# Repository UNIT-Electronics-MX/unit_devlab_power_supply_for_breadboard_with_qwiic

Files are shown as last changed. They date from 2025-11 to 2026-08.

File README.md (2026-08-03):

# DevLab: Power Supply for Breadboard with QWIIC

The Breadboard Power Supply with Load Decoy and QWIIC Connectors is a compact and versatile module designed to power electronic projects in a practical and safe way. It allows power to be supplied through QWIIC connectors or via USB-C chargers compatible with technologies such as Power Delivery (PD), Quick Charge (QC), or Battery Charging (BC).

<div align="center">
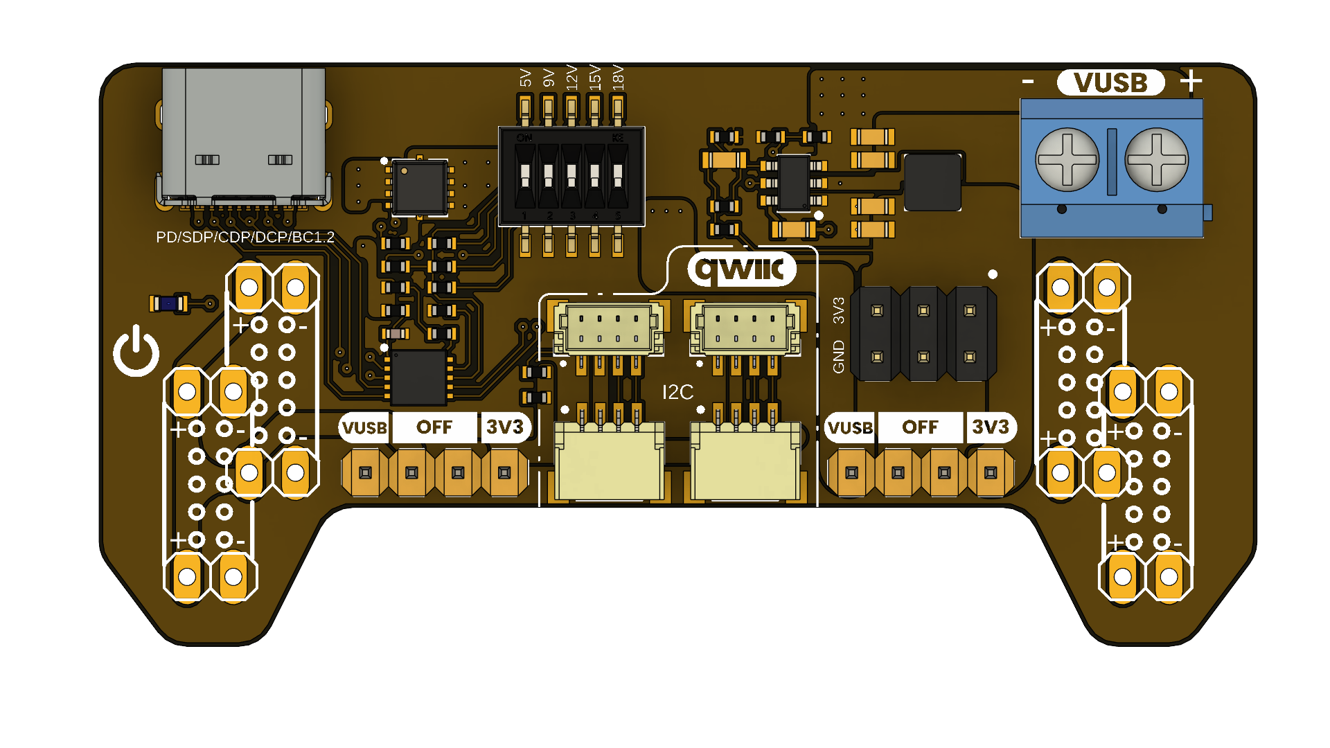
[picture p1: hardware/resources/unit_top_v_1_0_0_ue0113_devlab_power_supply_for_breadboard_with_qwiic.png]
Power Supply for Breadboard with QWIIC
  
  <p><em>Power Supply for Breadboard with QWIIC</em></p>
</div>

<div align="center">

### Quick Setup

[](https://wiki.uelectronics.com/wiki/unit_devlab_power_supply_for_breadboard_with_qwiic)
[](https://unit-electronics-mx.github.io/unit_devlab_power_supply_for_breadboard_with_qwiic/hardware/unit_datasheet_v_1_0_0_ue0113_Power_Supply_for_Breadboard_with_Qwii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)
[](https://uelectronics.com/producto/husb238-fuente-para-protoboard-con-senuelo-de-carga/)
[](#)

</div>

<div align="center" >

## Overview

| Feature | Description |
|---|---|
| USB PD IC | HUSB238 |
| Compatible voltages | 3.3V, 5V, 9V, 12V, 15V, 18V, 20V |
| Maximum output current | 5A |
| Power Supply | USB-C |
| Interfaces | I2C, PD3.0m type-C V1.4, Apple Divider 3, BC1.2 SDP, CDP and DCP |
| Form Factor | Designed for breadboards |
| Expansion Port | I2C connector for sensors and modules |

</div>

* **Note:** Output voltages and currents may vary with the characteristics of the power supply  

## Applications

- **Electrical consumption testing:** helps power prototypes while evaluating circuit behavior under different voltages or load conditions.

- **Breadboard prototype power supply:** allows test circuits to be powered in an organized way, using selectable voltage outputs and a regulated 3.3 V output.

- **Microcontroller testing:** useful for powering boards such as ESP32, Arduino, Raspberry Pi Pico, STM32, or other embedded systems that require stable power.

- **I2C sensor projects:** thanks to the QWIIC/STEMMA QT connectors, it makes it easier to connect compatible sensors without complex wiring.

- **USB-C PD powered projects:** allows modern USB-C chargers to be used to obtain different voltage profiles, such as 5 V, 9 V, 12 V, 15 V, or 20 V, depending on the configuration and the charger used.

- **Embedded systems development:** can be integrated during the development stage to power control circuits, sensors, and peripherals before designing a final power supply on a PCB.

- **Low- and medium-power actuator testing:** powers small motors, servos, relays, or actuators, always respecting the module’s current and voltage limits.

## Resources

- [Schematic Diagram](./hardware/unit_sch_v_1_0_0_ue0113_devlab_power_supply_for_breadboard_with_qwiic.pdf)
- [Pinout Diagram](./hardware/unit_pinout_v_1_0_0_ue00113_Power_Supply_for_Breadboard_with_Qwiic_en.pdf)
- [Getting Started Guide](./hardware/unit_datasheet_v_1_0_0_ue0113_Power_Supply_for_Breadboard_with_Qwiic.pdf)
- [Software examples](software/examples/README.md)

## 📝 License

All hardware and documentation in this project are licensed under the **MIT License**.  
See [`LICENSE.md`](LICENSE.md) for details.

<div align="center">
  <sub>Template created by UNIT Electronics</sub>
</div>

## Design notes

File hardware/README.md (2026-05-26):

# Hardware

<div align="center">
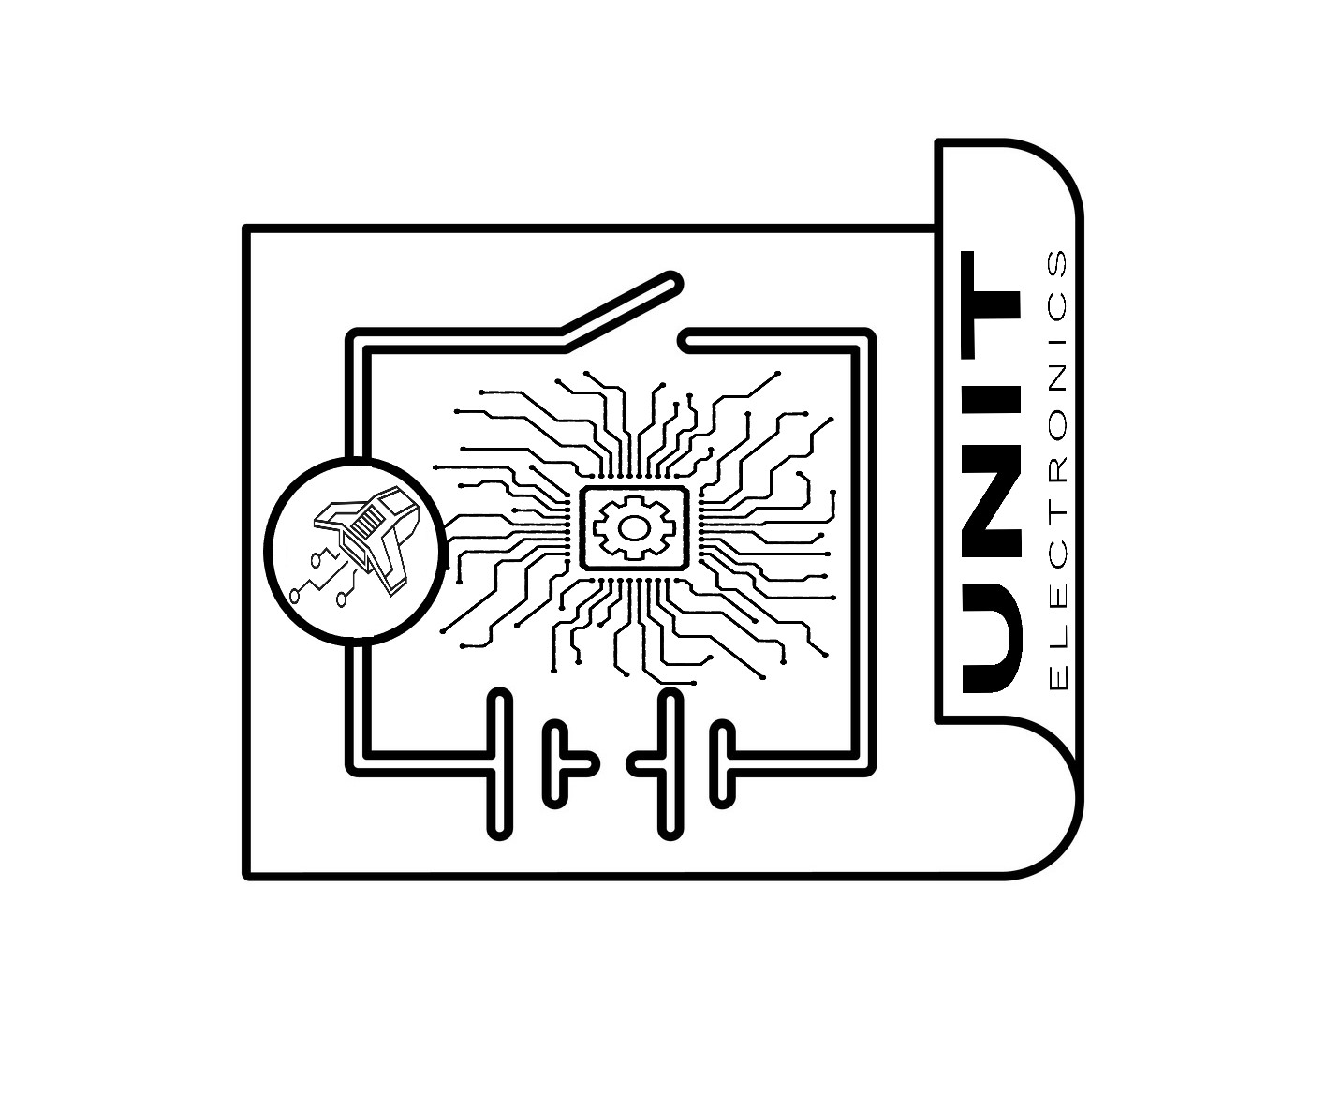
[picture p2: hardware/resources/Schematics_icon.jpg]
<a href="./unit_sch_v_1_0_0_ue0113_devlab_power_supply_for_breadboard_with_qwiic.pdf"><br/>Schematic</a>
</div>

## Key Technical Specifications

<div align="center">

| **Parameter** | **Description** | **Min** | **Typ** | **Max** | **Unit** |
|:---:|:---|:---:|:---:|:---:|:---:|
| Vin | USB Type-C PD input voltage | 5 | - | 20 | V |
| VBUS | USB PD negotiated output voltage | 5 | 9 / 12 / 15 | 20 | V |
| V3V3 | Regulated 3.3V output rail | 3.2 | 3.3 | 3.4 | V |
| I3V3 | Maximum 3.3V regulator output current | - | - | 2 | A |
| IBUS | Maximum breadboard output current | - | - | 5 | A |
| VIH | High-level input voltage for I²C | 0.7 × VCC | - | 5.5 | V |
| VIL | Low-level input voltage for I²C | - | - | 0.3 × VCC | V |
| ICC | Typical module supply current | - | 3.1 | - | mA |
| fI2C | Supported I²C communication frequency | 0 | 100 | 400 | kHz |
| TOPD | USB Power Delivery supported profiles | 5 | 9 / 12 / 15 | 20 | V |
| TAMB | Recommended operating ambient temperature | -20 | 25 | 85 | °C |

</div>

<br/>

> **Note 1:** USB Power Delivery voltage selection can be configured through the onboard DIP switch resistor network or dynamically through the HUSB238 I²C interface. I²C configuration has priority over DIP switch settings.

> **Note 2:** The 3.3V regulator output capability depends on thermal dissipation, PCB airflow, and input voltage conditions.

> **Note 3:** Qwiic/STEMMA QT connectors share the same I²C bus signals (3V3, GND, SDA, SCL) for daisy-chain operation.

> **Note 4:** The maximum VBUS/PD output current depends on the power capability, voltage profile, cable quality, and electrical characteristics of the connected USB Type-C PD power adapter.

> **Note 5:** The module integrates breadboard-compatible power rails with selectable VUSB and regulated 3.3V outputs.

</div>

* **Note:** Output voltages and currents may vary with the characteristics of the power supply

## Pinout

<div align="center">
<a href="./unit_pinout_v_1_0_0_ue00113_Power_Supply_for_Breadboard_with_Qwiic_en.pdf">
<br/>
Pinout
</a>
</div>
    
## Pin & Connector Layout

| Pin Label | Function | Notes |
|---|---|---|
| VUSB | USB Power Delivery output rail | Selectable PD voltage output (5V, 9V, 12V, 15V, 20V) |
| 3V3 | Regulated 3.3V output | Generated by onboard TPS54302 regulator |
| GND | Ground reference | Common ground for power and signals |
| SDA | I²C serial data line | Connected to Qwiic/STEMMA QT interface and HUSB238 |
| SCL | I²C serial clock line | Connected to Qwiic/STEMMA QT interface and HUSB238 |
| USB-C | USB Type-C PD input connector | Power input supporting USB Power Delivery |
| DIP SW | PD voltage selection switch | Selects PD negotiation voltage profile |
| QWIIC | Qwiic/STEMMA QT connector | JST 1.0 mm connector for I²C peripherals |
| VOUT | Breadboard power output | Output rail for external circuits and breadboards |
| GND OUT | Breadboard ground output | Ground rail for external circuits and breadboards |
| Header A | Breadboard interface header | Power rail connection for breadboard integration |
| Header B | Auxiliary power header | Provides VUSB, 3V3, and GND outputs |

> **Note:** The Qwiic/STEMMA QT connectors share the same SDA and SCL bus lines and are intended for daisy-chain I²C connectivity.

> **Note:** Only one jumper configuration should be used at a time to avoid electrical conflicts or damage.

</div>

## Dimensions

<div align="center">
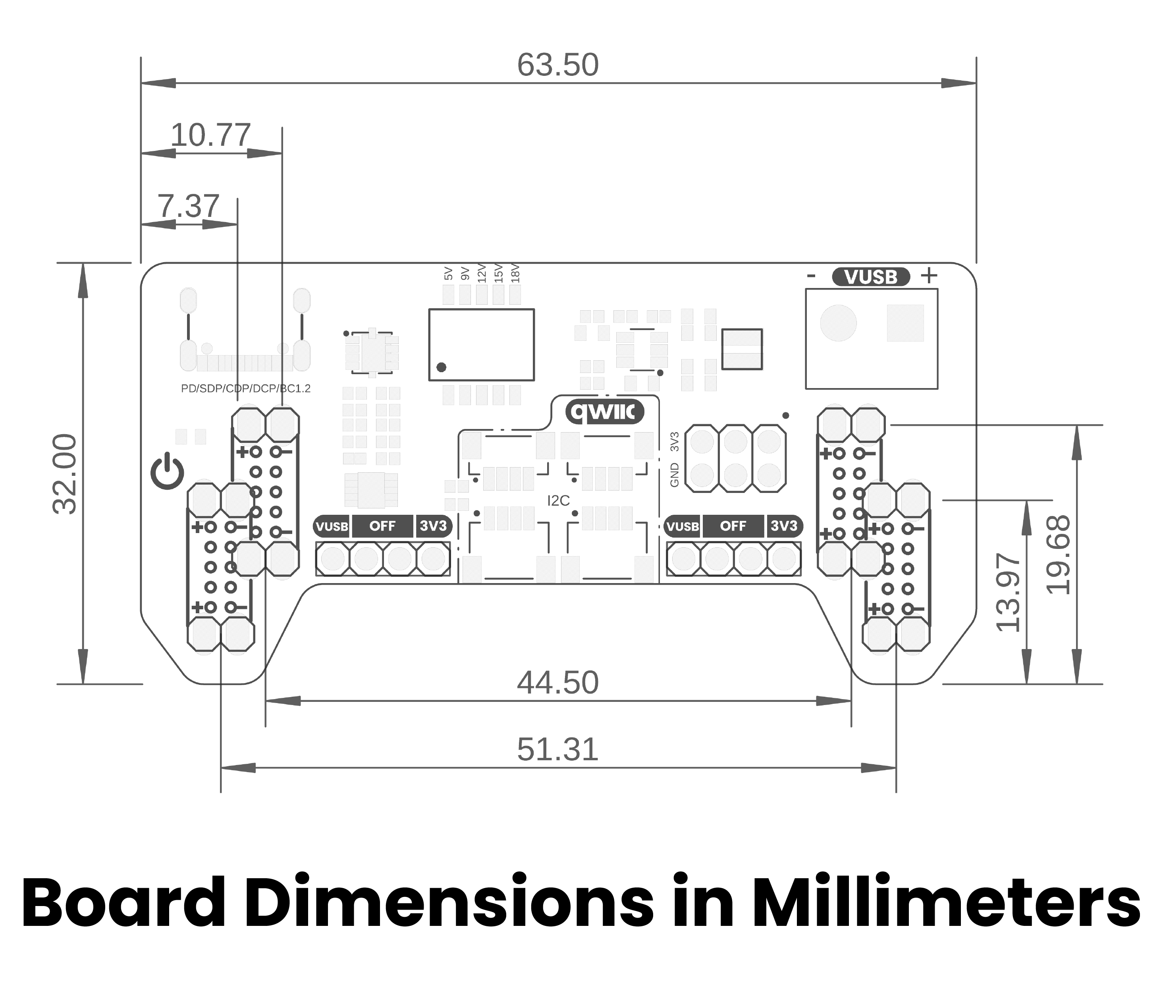
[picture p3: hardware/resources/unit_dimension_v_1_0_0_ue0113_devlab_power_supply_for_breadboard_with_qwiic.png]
<a href="./resources/unit_dimension_v_1_0_0_ue0113_devlab_power_supply_for_breadboard_with_qwiic.png"><br/> Dimensions</a>
</div>

## Topology

<div align="center">
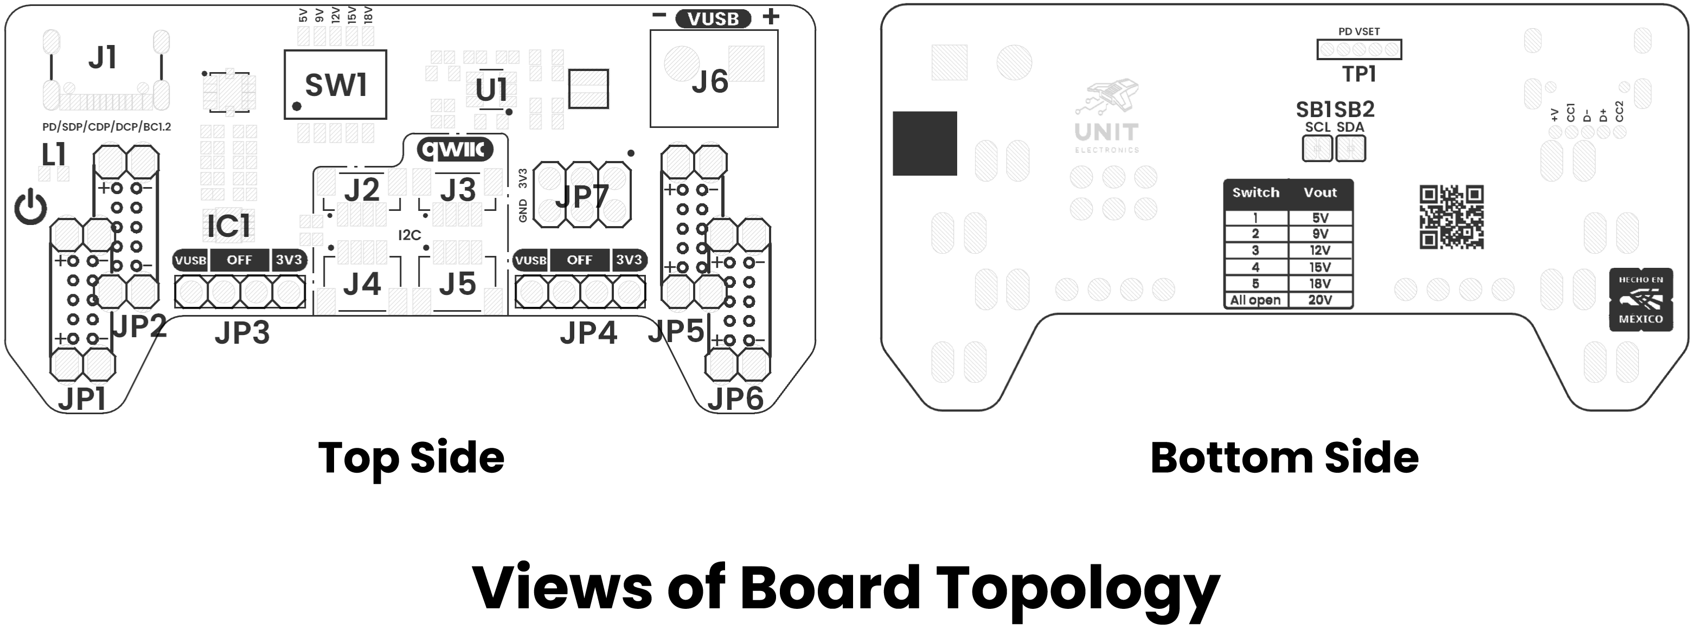
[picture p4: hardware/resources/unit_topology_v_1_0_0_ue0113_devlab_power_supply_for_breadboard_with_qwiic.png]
<a href="./resources/unit_topology_v_1_0_0_ue0113_devlab_power_supply_for_breadboard_with_qwiic.png"><br/> Topology</a>
<br/>
<br/>
<br/>

| Ref. | Description |
|---|---|
| J1 | USB Type-C Connector |
| L1 | Power On LED |
| IC1 | HUSB238 |
| SW1 | Dip Switch for voltage selector |
| U1 | TPS54302 3.3V Regulator |
| J6 | Screw Terminal Block output for VUSB |
| JP7 | Pin Header for 3V3 power supply |
| JP3 | Output voltage selector for the left side headers  |
| JP4 | Output voltage selector for the right side headers |
| JP1-JP2 | Left side output voltage headers for breadboard |
| JP5-JP6 | Right side output voltage headers for breadboard |

</div>

## Pin & Connector Layout
| Pin | Voltage Level | Function |
|---|---|---|
| VCC | 3.3 V – 5.5 V | Provides power to the on-board regulator and sensor core. |
| GND | 0 V | Common reference for power and signals. |
| SDA | 1.8 V to VCC  | Serial data line for I²C communications. |
| SCL | 1.8 V to VCC  | Serial clock line for I²C communications. |

> **Note:** The module also includes a Qwiic/STEMMA QT connector carrying the same four signals (VCC, GND, SDA, SCL) for effortless daisy-chaining.

# References

- <a href="./resources/unit_datasheet_v_1_0_0_ue0113_husb238.pdf">HUSB238 Datasheet </a>
- <a href="./resources/unit_datasheet_v_1_0_0_ue0113_tps54302.pdf">TPS54302 Datasheet </a>

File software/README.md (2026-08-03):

# Software

This directory contains the software examples for communicating with the
HUSB238 USB-C Power Delivery controller on the DevLab Power Supply for
Breadboard with Qwiic.

## Current support

The repository currently provides one C++ example:

- [`husb238_detection_only`](examples/cpp_examples/husb238_detection_only/husb238_detection_only.ino)
  detects the HUSB238 over I2C and reports the USB-C PD voltage profiles
  advertised by the connected power source.

The example is detection-only. It does not request a different voltage, change
the active USB-C PD contract, or control the 3.3 V output.

## Directory structure

```text
software/
├── README.md
└── examples/
    ├── README.md
    └── cpp_examples/
        └── husb238_detection_only/
            └── husb238_detection_only.ino
```

## Requirements

- A C++-compatible controller with an I2C interface
- **Adafruit HUSB238 Library**
- **Adafruit BusIO**
- A serial terminal configured for **115200 baud**
- A USB-C power adapter that supports USB Power Delivery
- A Qwiic/STEMMA QT cable or equivalent I2C connection

## Connection

Connect the external controller to the power-supply module through its
Qwiic/STEMMA QT port.

| Signal | Default controller pin | Description |
|---|---:|---|
| SDA | 6 | I2C data |
| SCL | 7 | I2C clock |
| 3.3 V | — | I2C logic supply |
| GND | — | Common ground |

The SDA and SCL values are example defaults for UNIT Electronics RP2040
controllers. If another controller is used, update these definitions in the
sketch:

```cpp
#define HUSB238_I2C_SDA 6
#define HUSB238_I2C_SCL 7
```

The HUSB238 uses `HUSB238_I2CADDR_DEFAULT`, as defined by the driver library.

## Running the example

1. Install the Adafruit HUSB238 Library and Adafruit BusIO in the C++
   development environment.
2. Connect the controller to the module over I2C.
3. Connect a USB-C PD power adapter to the module.
4. Open
   [`husb238_detection_only.ino`](examples/cpp_examples/husb238_detection_only/husb238_detection_only.ino)
   and select the correct target board and serial port.
5. Build and upload the sketch.
6. Open the serial terminal at 115200 baud.

When communication succeeds, the output lists the voltage profiles advertised
by the connected USB-C PD source:

```text
Initializing HUSB238...
HUSB238 detected.
Available USB-C PD voltages:
- 5 V
- 9 V
- 12 V
```

The available profiles depend on the connected adapter. If the controller
cannot communicate with the module, verify the I2C pins, power, ground, and
Qwiic/STEMMA QT connection.

## Voltage-selection behavior

The module can select a USB Power Delivery voltage through either the onboard
DIP-switch resistor network or the HUSB238 I2C interface. An I2C configuration
takes priority over the DIP-switch setting.

The DIP switch can request 5 V, 9 V, 12 V, 15 V, or 20 V when that profile is
supported by the connected adapter.

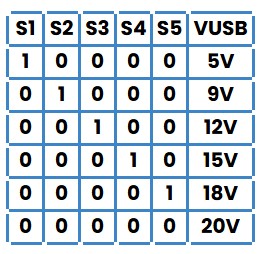
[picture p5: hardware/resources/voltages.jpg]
DIP-switch voltage selection


Always verify that the adapter, USB-C cable, selected voltage profile, and load
support the required voltage and current before powering a circuit.

## More information

- [Examples guide](examples/README.md)
- [Hardware documentation](../hardware/README.md)
- [HUSB238 datasheet](../hardware/resources/unit_datasheet_v_1_0_0_ue0113_husb238.pdf)
- [Module schematic](../hardware/unit_sch_v_1_0_0_ue0113_devlab_power_supply_for_breadboard_with_qwiic.pdf)

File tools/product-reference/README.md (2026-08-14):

# Product Reference build

The Power Supply for Breadboard with Qwiic (UE0113) Product Reference source
is maintained in Markdown under `chapters/`. Document metadata and chapter
order are defined in `book.yml`. Version 1.0.0 migrates the released V1.0
datasheet into editable source, using the board schematic, pinout, topology,
and component datasheets as supporting references.

## Local validation build

Requirements:

- Pandoc
- WeasyPrint

Run from the repository root and direct validation output outside the
repository:

```bash
./tools/product-reference/build.sh /tmp/ue0113-product-reference
```

The build produces:

```text
unit_product_reference_v_1_0_0_ue0113_power_supply_for_breadboard_with_qwiic.md
unit_product_reference_v_1_0_0_ue0113_power_supply_for_breadboard_with_qwiic.docx
unit_product_reference_v_1_0_0_ue0113_power_supply_for_breadboard_with_qwiic.html
unit_product_reference_v_1_0_0_ue0113_power_supply_for_breadboard_with_qwiic.pdf
```

GitHub Actions publishes the PDF and DOCX under `docs/hardware/`. Do not edit
generated documents or `docs/` manually.

The Markdown chapters are the editable source of truth for the generated
reference. The released V1.0 PDF remains available in `hardware/` as the
historical release. Board values and mappings must come from board-level
documentation; do not infer complete module limits from an individual
component datasheet. Chapter 9 records source scope and version control.

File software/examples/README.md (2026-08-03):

# Software examples

Each C++ sketch has its own directory whose name matches its main `.ino` file.
See the [software guide](../README.md) for dependencies, connection details,
configuration, and usage instructions.

```text
examples/
└── cpp_examples/
    └── husb238_detection_only/
        └── husb238_detection_only.ino
```

## C++: HUSB238 detection

The [`husb238_detection_only`](cpp_examples/husb238_detection_only/husb238_detection_only.ino)
sketch detects the module and prints the USB-C PD voltage profiles offered by
the attached source.

The example defaults to SDA pin `6` and SCL pin `7`. Change
`HUSB238_I2C_SDA` and `HUSB238_I2C_SCL` when using another controller.

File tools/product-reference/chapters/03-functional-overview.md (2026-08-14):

## **3 Functional Overview**

The module receives power from a USB-C PD source, negotiates a compatible
fixed profile through the HUSB238 controller, and distributes that negotiated
VUSB rail to the screw terminal and selectable breadboard headers. In parallel,
the TPS54302 converts VUSB to a regulated 3.3 V rail for logic and Qwiic
peripherals.

### **3.1 Power Distribution Architecture** {.section-page}

Board topology

The left and right breadboard rails have independent selectors. Each selector
can route VUSB, disconnect the rail, or route 3.3 V. This makes it possible to
use a higher PD voltage for one rail while retaining 3.3 V logic on the other.

| Selection | Function |
|---|---|
| `VUSB` | Routes the negotiated USB-C PD voltage to the rail |
| `OFF` | Disconnects the rail output |
| `3V3` | Routes the regulated 3.3 V rail to the rail |

### **3.2 USB-C Power Delivery** {.section-page}

The HUSB238 performs USB-C PD-sink negotiation with a compatible source. The
available profiles are determined by the charger and cable; selecting a
profile does not create a voltage that the source did not advertise. The
released datasheet describes 5 V, 9 V, 12 V, 15 V, and 20 V as the standard
profiles, and also mentions 18 V where that profile is offered by the source.

Use the onboard DIP switch for standalone configuration. When HUSB238 I²C
access is enabled, a host controller can monitor the connection and apply
dynamic selection; I²C configuration has priority over the DIP-switch setting.

### **3.3 Qwiic Expansion** {.section-page}

The Qwiic-compatible JST 1.0 mm connectors expose a shared 3.3 V I²C bus:
SDA, SCL, 3.3 V, and ground. Optional solder jumpers connect the HUSB238 to
that bus for monitoring and control. Leave those jumpers open when the
controller must remain isolated from the external Qwiic network.

The I²C bus is a 3.3 V logic domain. Do not apply VUSB to SDA, SCL, or the
Qwiic power pin.

### **3.4 Breadboard Integration** {.section-page}

The mechanical layout aligns with common 54 mm and 64 mm breadboard rail
formats. The two sides permit independent power assignment for cases such as:

| Left rail | Right rail | Typical use |
|---|---|---|
| 3.3 V | 3.3 V | Logic and sensor prototype |
| VUSB | 3.3 V | Mixed power and logic system |
| 12 V | 3.3 V | Motor driver with microcontroller |
| OFF | VUSB | Single high-voltage rail test |

The `12 V` example assumes that the source provides and the module has
selected that VUSB profile.

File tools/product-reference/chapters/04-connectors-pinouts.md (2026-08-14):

## **4 Connectors and Pinout**

General pinout

### **4.1 General Pinout Description** {.section-page}

| Label | Function | Notes |
|---|---|---|
| `VUSB` | USB PD output rail | Negotiated PD voltage; 5 V to 20 V according to the attached source and selected profile |
| `3V3` | Regulated output | Generated by the TPS54302 regulator |
| `GND` | Ground reference | Common reference for power and signals |
| `SDA` | I²C data | Qwiic/STEMMA QT bus; optional HUSB238 access |
| `SCL` | I²C clock | Qwiic/STEMMA QT bus; optional HUSB238 access |
| USB-C | PD input | Power input from a compatible USB-C PD source |
| DIP SW | PD configuration | Selects the standalone PD request configuration |
| Qwiic | I²C connector | JST 1.0 mm, 3.3 V peripheral interface |
| `VOUT` | Breadboard power output | Selected power rail for external circuits |
| `GND OUT` | Breadboard ground | Ground output for external circuits |
| Header A | Breadboard interface | Power-rail connection |
| Header B | Auxiliary power header | VUSB, 3.3 V, and ground outputs |

### **4.2 Qwiic I²C Connector** {.section-page}

| Pin | Voltage level | Function |
|---|---|---|
| VCC | 3.3 V module rail | Power for a connected 3.3 V-compatible peripheral |
| GND | 0 V | Common ground |
| SDA | 1.8 V to VCC | I²C serial data |
| SCL | 1.8 V to VCC | I²C serial clock |

The board's Qwiic/STEMMA QT connectors share one 3.3 V SDA/SCL bus and are
intended for daisy-chain connectivity. Use one voltage-selection jumper
configuration per rail; conflicting selections can damage the module or
connected hardware.

### **4.3 Output Connections** {.section-page}

The screw terminal exposes VUSB for a direct external connection. The
breadboard headers distribute the voltage selected by their corresponding left
or right selector. Disconnect power before changing selector jumpers or moving
the module between breadboards.

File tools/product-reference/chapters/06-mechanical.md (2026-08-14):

## **6 Mechanical Information**

Mechanical dimensions in millimeters

All dimensions in the drawing are in millimeters. The board is designed to
align with common 54 mm and 64 mm solderless-breadboard rail formats. Confirm
actual clearance around the USB-C connector, screw terminal, jumper caps, and
Qwiic cable before final assembly.

### **6.1 Installation Notes** {.section-page}

Support the board while inserting or removing it from a breadboard to avoid
bending headers. Do not use the Qwiic cable or USB-C cable as a mechanical
support. Keep adequate clearance for wiring attached to the VUSB terminal and
for heat dissipation from the regulator under load.

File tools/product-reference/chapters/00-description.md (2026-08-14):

## **Description**

The DevLab Power Supply for Breadboard with Qwiic is a USB Type-C-powered
power-distribution module for breadboard-based electronic prototyping. It acts
as a USB Power Delivery (PD) sink, negotiates a profile from a compatible
source, and routes the negotiated VUSB rail to selectable breadboard outputs.
An onboard TPS54302 buck regulator supplies a separate 3.3 V rail.

Power Supply for Breadboard with Qwiic top view

### **Applications**

- Breadboard power distribution and mixed-voltage prototyping
- USB-C PD source and cable evaluation
- Embedded-system, sensor, and peripheral development
- Laboratory education, validation, and early hardware testing

### **Hardware Features**

- USB Type-C PD input with HUSB238 PD-sink controller
- Selectable VUSB profiles supported by the attached PD source
- TPS54302-based 3.3 V output rail
- Independent left and right breadboard-rail selection
- Screw-terminal and header outputs for VUSB, 3.3 V, and ground
- Qwiic-compatible I²C connectors for 3.3 V peripherals
- DIP-switch PD configuration and optional HUSB238 I²C access

The module is mechanically intended for common 54 mm and 64 mm breadboard
rail formats. Output voltage and available current depend on the negotiated PD
profile, source, cable, thermal conditions, and external load.

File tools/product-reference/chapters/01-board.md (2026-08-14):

## **1 The Board**

The Power Supply for Breadboard with Qwiic provides a compact power entry and
distribution point for solderless breadboards. A USB-C PD source supplies the
module. The selected VUSB rail and the regulated 3.3 V rail can be assigned to
the two breadboard sides independently, which supports both single-voltage and
mixed-voltage prototypes.

### **1.1 Board Identification** {.section-page}

| Item | Value |
|---|---|
| Product | Power Supply for Breadboard with Qwiic |
| Manufacturer part number | UE0113 |
| Product family | UNIT Electronics DevLab |
| Product type | USB-C PD breadboard power-distribution module |
| Hardware revision | V1.0 |
| Product Reference | Version 1.0.0 |
| PD controller | HUSB238 |
| 3.3 V regulator | TPS54302 |

### **1.2 Included and Recommended Items** {.section-page}

The released V1.0 datasheet lists the following accessory items: 16 single-row
male headers, one Qwiic 4-pin JST 1.0 mm harness, and two jumper caps.

For safe operation, use a USB-C charger that supports the needed PD profile, a
USB-C cable rated for the expected voltage and current, and a breadboard with
the appropriate rail spacing. Verify the source profile before connecting a
load.

### **1.3 Main Assemblies** {.section-page}

| RefDes | Component or connector | Function |
|---|---|---|
| J1 | USB Type-C connector | PD power input |
| IC1 | HUSB238 | PD negotiation controller |
| SW1 | DIP switch | PD voltage-profile selection |
| U1 | TPS54302 | 3.3 V buck regulator |
| L1 | Power LED | Power indication |
| J6 | Screw terminal | VUSB output access |
| JP7 | Pin header | 3.3 V output access |
| JP3 / JP4 | Selector headers | Left and right rail-voltage selection |
| JP1 / JP2 | Left headers | Breadboard power connection |
| JP5 / JP6 | Right headers | Breadboard power connection |

### **1.4 Board Views** {.section-page}

Top view

Bottom view

### **1.5 Handling** {.section-page}

Disconnect USB-C power before moving rail-selection jumpers, inserting the
board into a breadboard, or changing wiring. Keep high-voltage VUSB wiring
away from the 3.3 V logic rail and confirm polarity before connecting a load.

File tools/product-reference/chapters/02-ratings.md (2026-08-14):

## **2 Ratings**

The following values are migrated from the released V1.0 product datasheet.
They describe intended module operation and do not replace the limits in the
HUSB238 or TPS54302 component datasheets.

### **2.1 Recommended Operating Conditions** {.section-page}

| Parameter | Description | Min | Typ | Max | Unit |
|---|---|---:|---:|---:|---|
| `VIN` | USB Type-C PD input voltage | 5 | — | 20 | V |
| `VBUS` | USB PD negotiated output voltage | 5 | 9 / 12 / 15 | 20 | V |
| `V3V3` | Regulated 3.3 V output rail | 3.2 | 3.3 | 3.4 | V |
| `I3V3` | 3.3 V regulator output current | — | — | 2 | A |
| `IBUS` | Breadboard output current | — | — | 5 | A |
| `VIH` | I²C high-level input voltage | 0.7 × VCC | — | 5.5 | V |
| `VIL` | I²C low-level input voltage | — | — | 0.3 × VCC | V |
| `ICC` | Module supply current | — | 3.1 | — | mA |
| `fI2C` | I²C communication frequency | 0 | 100 | 400 | kHz |
| `TOPD` | USB PD supported profiles | 5 | 9 / 12 / 15 | 20 | V |
| `TAMB` | Recommended ambient temperature | -20 | 25 | 85 | °C |

### **2.2 Electrical Notes** {.section-page}

1. PD voltage can be selected through the onboard DIP-switch resistor network
   or dynamically through the HUSB238 I²C interface. I²C configuration takes
   precedence over DIP-switch selection.
2. The 3.3 V output capability depends on input voltage, thermal dissipation,
   board airflow, and load conditions.
3. Qwiic/STEMMA QT connectors share 3.3 V, ground, SDA, and SCL for daisy-chain
   operation.
4. VBUS output current depends on the available source profile, cable, and
   electrical characteristics of the attached PD power adapter.
5. For stable 3.3 V regulation, use a 9 V, 12 V, 15 V, or 20 V PD profile. At
   5 V, the input must remain above 4.5 V under load to avoid TPS54302 UVLO.

### **2.3 Power-Domain Scope** {.section-page}

`VUSB` is the negotiated USB-C PD output rail. `3V3` is generated by the
TPS54302 and is intended for low-voltage logic and Qwiic peripherals. Both
rails share ground but must not be treated as interchangeable. Available
current for a specific setup is limited by the PD source, cable, selected
profile, onboard consumption, temperature, and connected load.

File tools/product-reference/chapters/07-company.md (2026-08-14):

## **7 Company Information**

| Item | Value |
|---|---|
| Company | UNIT Electronics |
| Website | <https://uelectronics.com/> |
| Address | Salvador 19, Cuauhtémoc, 06000, Mexico City, CDMX, Mexico |
| Product family | DevLab |

For product support, current documentation, and software examples, use the
product wiki and repository listed in the next chapter.

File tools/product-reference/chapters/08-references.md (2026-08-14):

## **8 Reference Documentation**

| Reference | Link or repository file |
|---|---|
| Product wiki | [Power Supply for Breadboard with Qwiic wiki](https://wiki.uelectronics.com/wiki/unit_devlab_power_supply_for_breadboard_with_qwiic) |
| Source repository | [UNIT-Electronics-MX/unit_devlab_power_supply_for_breadboard_with_qwiic](https://github.com/UNIT-Electronics-MX/unit_devlab_power_supply_for_breadboard_with_qwiic) |
| Board schematic | [V1.0 schematic](https://github.com/UNIT-Electronics-MX/unit_devlab_power_supply_for_breadboard_with_qwiic/blob/main/hardware/unit_sch_v_1_0_0_ue0113_devlab_power_supply_for_breadboa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) |
| General pinout | [English pinout](https://github.com/UNIT-Electronics-MX/unit_devlab_power_supply_for_breadboard_with_qwiic/blob/main/hardware/unit_pinout_v_1_0_0_ue00113_Power_Supply_for_Breadboard_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) |
| HUSB238 controller | `hardware/resources/unit_datasheet_v_1_0_0_ue0113_husb238.pdf` |
| TPS54302 regulator | `hardware/resources/unit_datasheet_v_1_0_0_ue0113_tps54302.pdf` |
| Arduino IDE | [arduino.cc/en/software](https://www.arduino.cc/en/software) |

Component datasheets describe the individual devices. The ratings and
mechanical information in this reference remain specific to the UE0113 module.

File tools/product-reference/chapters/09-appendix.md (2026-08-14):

## **9 Appendix**

### **9.1 Source Migration** {.section-page}

This editable product reference is migrated from the released PDF:

`hardware/unit_datasheet_v_1_0_0_ue0113_Power_Supply_for_Breadboard_with_Qwiic.pdf`

The original PDF is retained as a released historical artifact. The Markdown
chapters under `tools/product-reference/chapters/` are the source for future
generated PDF and DOCX editions.

### **9.2 Documentation Scope** {.section-page}

The module's negotiated VUSB output depends on the USB-C PD source and cable.
The listed component ratings do not independently establish all module-level
limits. Before high-voltage or high-current use, verify the selected profile,
measure the output, and account for all connected hardware.

The released V1.0 datasheet mentions an 18 V PD profile in descriptive text,
while its ratings tables enumerate 5 V, 9 V, 12 V, 15 V, and 20 V. This
reference treats 18 V as source-dependent rather than as a guaranteed standard
profile.

### **9.3 Document Control** {.section-page}

| Item | Value |
|---|---|
| Product reference version | 1.0.0 |
| Hardware revision | V1.0 |
| Manufacturer part number | UE0113 |
| Released datasheet date | 2026-06-30 |
| Editable source | `tools/product-reference/` |

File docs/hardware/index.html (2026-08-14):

UNIT Electronics · DevLab

# Power Supply for Breadboard with Qwiic

Direct links to hardware documentation and product files for use in external platforms.

24 files 10 images 11 formats 120.8 MB total

Search hardware resources

## Product documents

3 files

DOCX 3.0 MB

### Product Reference

Editable product reference

unit_product_reference_v_1_0_0_ue0113_power_supply_for_breadboard_with_qwiic.docx

Copy link Open file

PDF 3.2 MB

### Product Reference

Publication-ready product reference

unit_product_reference_v_1_0_0_ue0113_power_supply_for_breadboard_with_qwiic.pdf

Copy link Open file

PDF 68.5 KB

### Schematic

Electrical schematic

unit_sch_v_1_0_0_ue0113_devlab_power_supply_for_breadboard_with_qwiic.pdf

Copy link Open file

## Pinouts

6 files

JPG 4.1 MB

### Pinout — English

Connector and signal reference in English

resources/unit_pinout_v_1_0_0_ue00113_Power_Supply_for_Breadboard_with_Qwiic_en.jpg

Copy link Open file

PDF 3.4 MB

### Pinout — English

Connector and signal reference in English

unit_pinout_v_1_0_0_ue00113_Power_Supply_for_Breadboard_with_Qwiic_en.pdf

Copy link Open file

PNG 2.0 MB

### Pinout — English

Connector and signal reference in English

resources/unit_pinout_v_1_0_0_ue00113_Power_Supply_for_Breadboard_with_Qwiic_en.png

Copy link Open file

JPG 4.2 MB

### Pinout — Spanish

Connector and signal reference in Spanish

resources/unit_pinout_v_1_0_0_ue00113_Power_Supply_for_Breadboard_with_Qwiic_es.jpg

Copy link Open file

PDF 3.4 MB

### Pinout — Spanish

Connector and signal reference in Spanish

resources/unit_pinout_v_1_0_0_ue00113_Power_Supply_for_Breadboard_with_Qwiic_es.pdf

Copy link Open file

PNG 2.0 MB

### Pinout — Spanish

Connector and signal reference in Spanish

resources/unit_pinout_v_1_0_0_ue00113_Power_Supply_for_Breadboard_with_Qwiic_es.png

Copy link Open file

## Board views

4 files

PNG 281.4 KB

### Board Topology

Functional board layout

resources/unit_topology_v_1_0_0_ue0113_devlab_power_supply_for_breadboard_with_qwiic.png

Copy link Open file

PNG 227.3 KB

### Bottom View

Bottom-side board view

resources/unit_btm_v_1_0_0_ue0113_devlab_power_supply_for_breadboard_with_qwiic.png

Copy link Open file

PNG 246.2 KB

### Mechanical Dimensions

Board outline and dimensions

resources/unit_dimension_v_1_0_0_ue0113_devlab_power_supply_for_breadboard_with_qwiic.png

Copy link Open file

PNG 367.6 KB

### Top View

Top-side board view

resources/unit_top_v_1_0_0_ue0113_devlab_power_supply_for_breadboard_with_qwiic.png

Copy link Open file

## CAD and design files

2 files

STEP 46.1 MB

### 3D CAD Model

STEP mechanical model

mechanics/unit_3d_v_1_0_0_ue0113_Power_Supply_for_Breadboard.step

Copy link Open file

GLB 11.9 MB

### 3D Web Model

Interactive GLB model

mechanics/unit_3d_v_1_0_0_ue0113_Power_Supply_for_Breadboard.glb

Copy link Open file

## Other resources

9 files

JSON 1.1 KB

### Catalog

Hardware resource

mechanics/catalog.json

Copy link Open file

MD 5.8 KB

### Hardware README

Hardware overview and source notes

README.md

Copy link Open file

HTML 28.1 KB

### Index

Hardware resource

index.html

Copy link Open file

F3Z 17.7 MB

### Unit 3D V 1 0 0 Ue0113 Power Supply For Breadboard

Hardware resource

mechanics/unit_3d_v_1_0_0_ue0113_Power_Supply_for_Breadboard.f3z

Copy link Open file

SVG 12.4 MB

### Unit 3D V 1 0 0 Ue0113 Power Supply For Breadboard

Hardware resource

mechanics/unit_3d_v_1_0_0_ue0113_Power_Supply_for_Breadboard.svg

Copy link Open file

PDF 1.3 MB

### Unit Datasheet V 1 0 0 Ue0113 Husb238

Hardware resource

resources/unit_datasheet_v_1_0_0_ue0113_husb238.pdf

Copy link Open file

PDF 2.6 MB

### Unit Datasheet V 1 0 0 Ue0113 Power Supply For Breadboard With Qwiic

Hardware resource

unit_datasheet_v_1_0_0_ue0113_Power_Supply_for_Breadboard_with_Qwiic.pdf

Copy link Open file

PDF 2.3 MB

### Unit Datasheet V 1 0 0 Ue0113 Tps54302

Hardware resource

resources/unit_datasheet_v_1_0_0_ue0113_tps54302.pdf

Copy link Open file

JPG 26.1 KB

### Voltages

Hardware resource

resources/voltages.jpg

Copy link Open file

No resources match your search.

UNIT Electronics hardware resources

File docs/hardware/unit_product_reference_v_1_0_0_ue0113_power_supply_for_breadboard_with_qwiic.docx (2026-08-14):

# Power Supply for Breadboard with Qwiic

Product Reference Manual — Hardware Revision V1.0

UNIT Electronics

2026-06-30

## Contents

- Description
  - Applications
  - Hardware Features
- 1 The Board
  - 1.1 Board Identification {.section-page}
  - 1.2 Included and Recommended Items {.section-page}
  - 1.3 Main Assemblies {.section-page}
  - 1.4 Board Views {.section-page}
  - 1.5 Handling {.section-page}
- 2 Ratings
  - 2.1 Recommended Operating Conditions {.section-page}
  - 2.2 Electrical Notes {.section-page}
  - 2.3 Power-Domain Scope {.section-page}
- 3 Functional Overview
  - 3.1 Power Distribution Architecture {.section-page}
  - 3.2 USB-C Power Delivery {.section-page}
  - 3.3 Qwiic Expansion {.section-page}
  - 3.4 Breadboard Integration {.section-page}
- 4 Connectors and Pinout
  - 4.1 General Pinout Description {.section-page}
  - 4.2 Qwiic I²C Connector {.section-page}
  - 4.3 Output Connections {.section-page}
- 5 Board Operation
  - 5.1 Initial Power-Up {.section-page}
  - 5.2 Standalone PD Selection {.section-page}
  - 5.3 I²C Monitoring with Arduino {.section-page}
  - 5.4 Operational Precautions {.section-page}
- 6 Mechanical Information
  - 6.1 Installation Notes {.section-page}
- 7 Company Information
- 8 Reference Documentation
- 9 Appendix
  - 9.1 Source Migration {.section-page}
  - 9.2 Documentation Scope {.section-page}
  - 9.3 Document Control {.section-page}

## Description

The DevLab Power Supply for Breadboard with Qwiic is a USB Type-C-powered power-distribution module for breadboard-based electronic prototyping. It acts as a USB Power Delivery (PD) sink, negotiates a profile from a compatible source, and routes the negotiated VUSB rail to selectable breadboard outputs. An onboard TPS54302 buck regulator supplies a separate 3.3 V rail.


Power Supply for Breadboard with Qwiic top view

### Applications

- Breadboard power distribution and mixed-voltage prototyping
- USB-C PD source and cable evaluation
- Embedded-system, sensor, and peripheral development
- Laboratory education, validation, and early hardware testing

### Hardware Features

- USB Type-C PD input with HUSB238 PD-sink controller
- Selectable VUSB profiles supported by the attached PD source
- TPS54302-based 3.3 V output rail
- Independent left and right breadboard-rail selection
- Screw-terminal and header outputs for VUSB, 3.3 V, and ground
- Qwiic-compatible I²C connectors for 3.3 V peripherals
- DIP-switch PD configuration and optional HUSB238 I²C access

The module is mechanically intended for common 54 mm and 64 mm breadboard rail formats. Output voltage and available current depend on the negotiated PD profile, source, cable, thermal conditions, and external load.

## 1 The Board

The Power Supply for Breadboard with Qwiic provides a compact power entry and distribution point for solderless breadboards. A USB-C PD source supplies the module. The selected VUSB rail and the regulated 3.3 V rail can be assigned to the two breadboard sides independently, which supports both single-voltage and mixed-voltage prototypes.

### 1.1 Board Identification

Item | Value
Product | Power Supply for Breadboard with Qwiic
Manufacturer part number | UE0113
Product family | UNIT Electronics DevLab
Product type | USB-C PD breadboard power-distribution module
Hardware revision | V1.0
Product Reference | Version 1.0.0
PD controller | HUSB238
3.3 V regulator | TPS54302

### 1.2 Included and Recommended Items

The released V1.0 datasheet lists the following accessory items: 16 single-row male headers, one Qwiic 4-pin JST 1.0 mm harness, and two jumper caps.

For safe operation, use a USB-C charger that supports the needed PD profile, a USB-C cable rated for the expected voltage and current, and a breadboard with the appropriate rail spacing. Verify the source profile before connecting a load.

### 1.3 Main Assemblies

RefDes | Component or connector | Function
J1 | USB Type-C connector | PD power input
IC1 | HUSB238 | PD negotiation controller
SW1 | DIP switch | PD voltage-profile selection
U1 | TPS54302 | 3.3 V buck regulator
L1 | Power LED | Power indication
J6 | Screw terminal | VUSB output access
JP7 | Pin header | 3.3 V output access
JP3 / JP4 | Selector headers | Left and right rail-voltage selection
JP1 / JP2 | Left headers | Breadboard power connection
JP5 / JP6 | Right headers | Breadboard power connection

### 1.4 Board Views

Top view

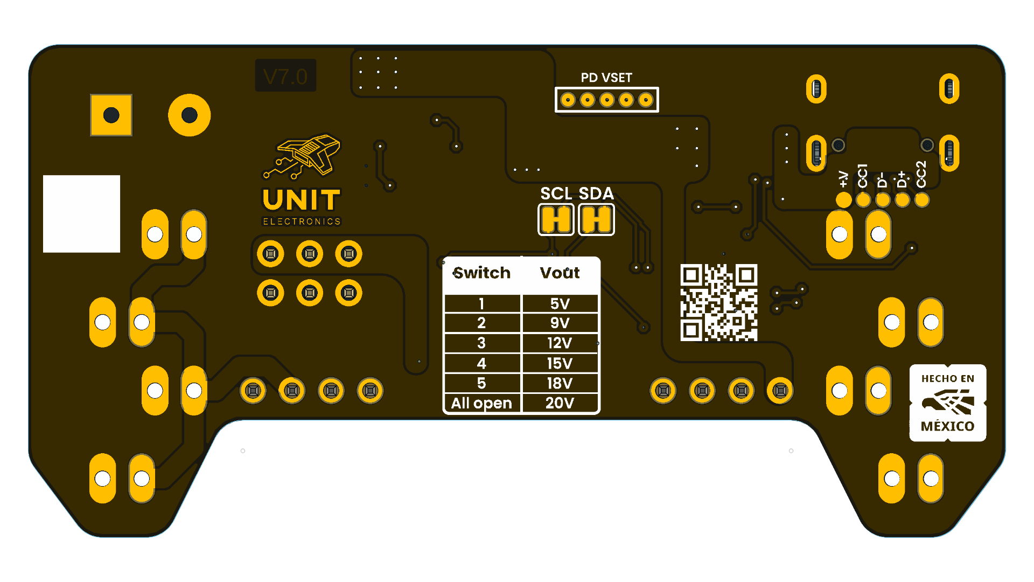
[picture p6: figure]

Bottom view

### 1.5 Handling

Disconnect USB-C power before moving rail-selection jumpers, inserting the board into a breadboard, or changing wiring. Keep high-voltage VUSB wiring away from the 3.3 V logic rail and confirm polarity before connecting a load.

## 2 Ratings

The following values are migrated from the released V1.0 product datasheet. They describe intended module operation and do not replace the limits in the HUSB238 or TPS54302 component datasheets.

### 2.1 Recommended Operating Conditions

Parameter | Description | Min | Typ | Max | Unit
VIN | USB Type-C PD input voltage | 5 | — | 20 | V
VBUS | USB PD negotiated output voltage | 5 | 9 / 12 / 15 | 20 | V
V3V3 | Regulated 3.3 V output rail | 3.2 | 3.3 | 3.4 | V
I3V3 | 3.3 V regulator output current | — | — | 2 | A
IBUS | Breadboard output current | — | — | 5 | A
VIH | I²C high-level input voltage | 0.7 × VCC | — | 5.5 | V
VIL | I²C low-level input voltage | — | — | 0.3 × VCC | V
ICC | Module supply current | — | 3.1 | — | mA
fI2C | I²C communication frequency | 0 | 100 | 400 | kHz
TOPD | USB PD supported profiles | 5 | 9 / 12 / 15 | 20 | V
TAMB | Recommended ambient temperature | -20 | 25 | 85 | °C

### 2.2 Electrical Notes

1. PD voltage can be selected through the onboard DIP-switch resistor network or dynamically through the HUSB238 I²C interface. I²C configuration takes precedence over DIP-switch selection.
2. The 3.3 V output capability depends on input voltage, thermal dissipation, board airflow, and load conditions.
3. Qwiic/STEMMA QT connectors share 3.3 V, ground, SDA, and SCL for daisy-chain operation.
4. VBUS output current depends on the available source profile, cable, and electrical characteristics of the attached PD power adapter.
5. For stable 3.3 V regulation, use a 9 V, 12 V, 15 V, or 20 V PD profile. At 5 V, the input must remain above 4.5 V under load to avoid TPS54302 UVLO.

### 2.3 Power-Domain Scope

VUSB is the negotiated USB-C PD output rail. 3V3 is generated by the TPS54302 and is intended for low-voltage logic and Qwiic peripherals. Both rails share ground but must not be treated as interchangeable. Available current for a specific setup is limited by the PD source, cable, selected profile, onboard consumption, temperature, and connected load.

## 3 Functional Overview

The module receives power from a USB-C PD source, negotiates a compatible fixed profile through the HUSB238 controller, and distributes that negotiated VUSB rail to the screw terminal and selectable breadboard headers. In parallel, the TPS54302 converts VUSB to a regulated 3.3 V rail for logic and Qwiic peripherals.

### 3.1 Power Distribution Architecture


Board topology

The left and right breadboard rails have independent selectors. Each selector can route VUSB, disconnect the rail, or route 3.3 V. This makes it possible to use a higher PD voltage for one rail while retaining 3.3 V logic on the other.

Selection | Function
VUSB | Routes the negotiated USB-C PD voltage to the rail
OFF | Disconnects the rail output
3V3 | Routes the regulated 3.3 V rail to the rail

### 3.2 USB-C Power Delivery

The HUSB238 performs USB-C PD-sink negotiation with a compatible source. The available profiles are determined by the charger and cable; selecting a profile does not create a voltage that the source did not advertise. The released datasheet describes 5 V, 9 V, 12 V, 15 V, and 20 V as the standard profiles, and also mentions 18 V where that profile is offered by the source.

Use the onboard DIP switch for standalone configuration. When HUSB238 I²C access is enabled, a host controller can monitor the connection and apply dynamic selection; I²C configuration has priority over the DIP-switch setting.

### 3.3 Qwiic Expansion

The Qwiic-compatible JST 1.0 mm connectors expose a shared 3.3 V I²C bus: SDA, SCL, 3.3 V, and ground. Optional solder jumpers connect the HUSB238 to that bus for monitoring and control. Leave those jumpers open when the controller must remain isolated from the external Qwiic network.

The I²C bus is a 3.3 V logic domain. Do not apply VUSB to SDA, SCL, or the Qwiic power pin.

### 3.4 Breadboard Integration

The mechanical layout aligns with common 54 mm and 64 mm breadboard rail formats. The two sides permit independent power assignment for cases such as:

Left rail | Right rail | Typical use
3.3 V | 3.3 V | Logic and sensor prototype
VUSB | 3.3 V | Mixed power and logic system
12 V | 3.3 V | Motor driver with microcontroller
OFF | VUSB | Single high-voltage rail test

The 12 V example assumes that the source provides and the module has selected that VUSB profile.

## 4 Connectors and Pinout

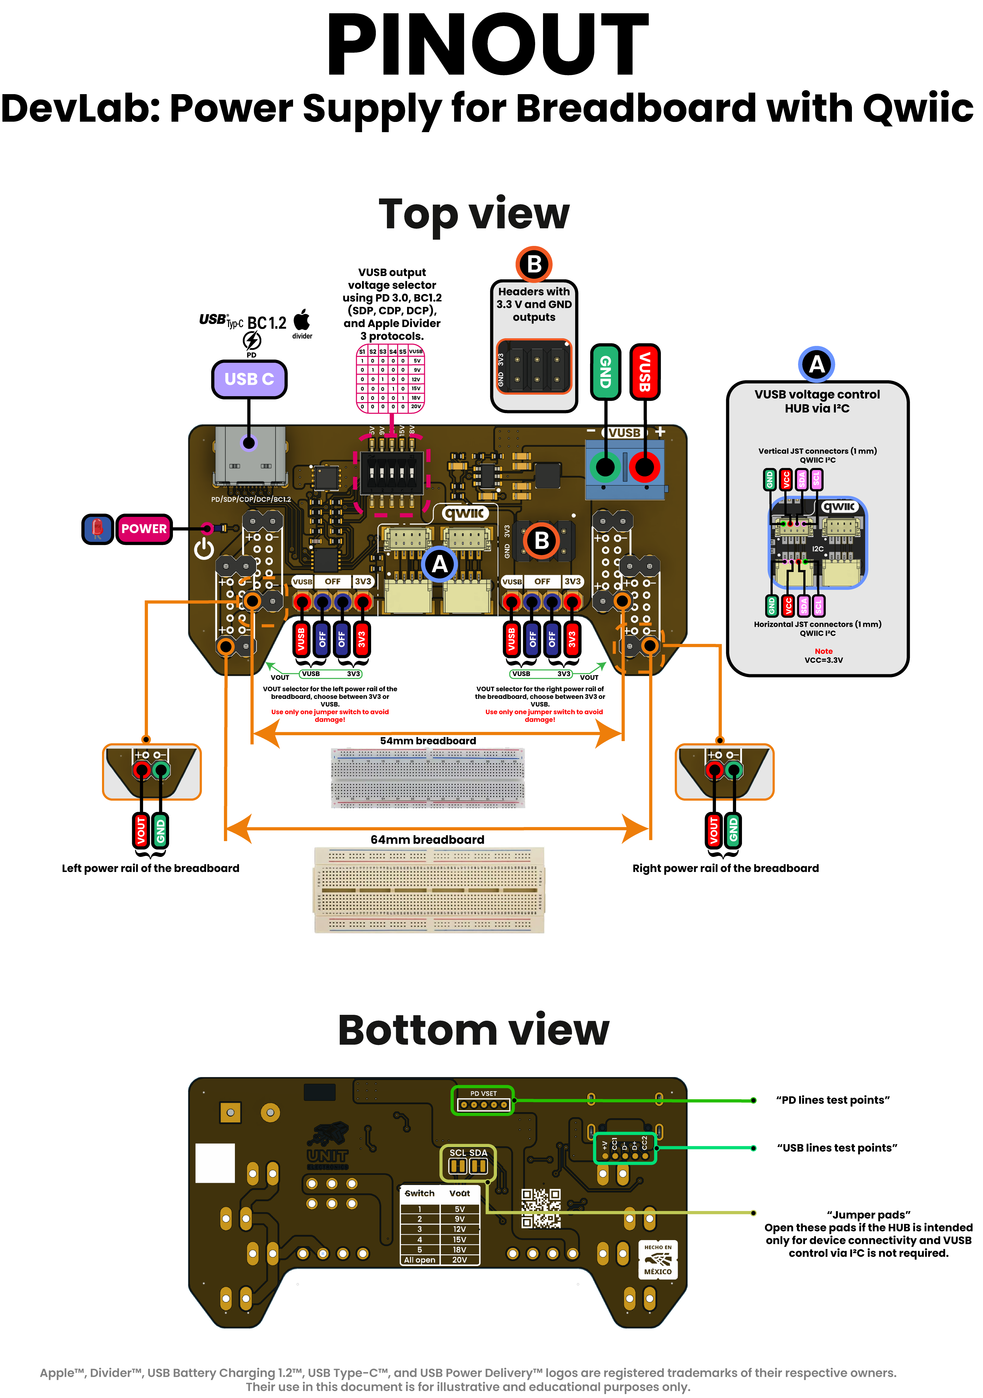
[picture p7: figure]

General pinout

### 4.1 General Pinout Description

Label | Function | Notes
VUSB | USB PD output rail | Negotiated PD voltage; 5 V to 20 V according to the attached source and selected profile
3V3 | Regulated output | Generated by the TPS54302 regulator
GND | Ground reference | Common reference for power and signals
SDA | I²C data | Qwiic/STEMMA QT bus; optional HUSB238 access
SCL | I²C clock | Qwiic/STEMMA QT bus; optional HUSB238 access
USB-C | PD input | Power input from a compatible USB-C PD source
DIP SW | PD configuration | Selects the standalone PD request configuration
Qwiic | I²C connector | JST 1.0 mm, 3.3 V peripheral interface
VOUT | Breadboard power output | Selected power rail for external circuits
GND OUT | Breadboard ground | Ground output for external circuits
Header A | Breadboard interface | Power-rail connection
Header B | Auxiliary power header | VUSB, 3.3 V, and ground outputs

### 4.2 Qwiic I²C Connector

Pin | Voltage level | Function
VCC | 3.3 V module rail | Power for a connected 3.3 V-compatible peripheral
GND | 0 V | Common ground
SDA | 1.8 V to VCC | I²C serial data
SCL | 1.8 V to VCC | I²C serial clock

The board’s Qwiic/STEMMA QT connectors share one 3.3 V SDA/SCL bus and are intended for daisy-chain connectivity. Use one voltage-selection jumper configuration per rail; conflicting selections can damage the module or connected hardware.

### 4.3 Output Connections

The screw terminal exposes VUSB for a direct external connection. The breadboard headers distribute the voltage selected by their corresponding left or right selector. Disconnect power before changing selector jumpers or moving the module between breadboards.

## 5 Board Operation

### 5.1 Initial Power-Up

1. With USB-C disconnected, set both breadboard-rail selectors to OFF.
2. Insert the module in the intended breadboard position and inspect that each header aligns with the intended power rail.
3. Connect a compatible USB-C PD source and cable.
4. Confirm the negotiated VUSB profile before connecting a load.
5. Set each rail independently to VUSB, 3V3, or leave it OFF.
6. Verify voltage and polarity with a meter before connecting sensitive or high-current circuitry.

### 5.2 Standalone PD Selection

The onboard DIP switch configures the HUSB238 request when no external I²C controller overrides it. Use only profiles supported by the connected source. An unavailable request must not be assumed to result in the selected voltage; measure VUSB before use.

### 5.3 I²C Monitoring with Arduino

When the optional HUSB238-to-Qwiic connections are enabled, an external 3.3 V microcontroller can access the controller through I²C. The released example uses an ESP32-compatible controller with SDA on GPIO6, SCL on GPIO7, and the default HUSB238 address 0x08.

Install the Adafruit_HUSB238 library and use the supplied example:

software/examples/cpp_examples/husb238_detection_only/husb238_detection_only.ino

The example initializes I²C, detects the HUSB238, and reports the PD profiles advertised by the attached source. It is a detection example; it does not validate the connected load or replace a voltage measurement.

### 5.4 Operational Precautions

- Do not change rail jumpers while the module is powered.
- Keep the VUSB rail isolated from 3.3 V-only devices and I²C signals.
- Use a cable and PD source rated for the requested voltage and expected load.
- The maximum usable output current is installation-dependent; respect source, cable, regulator, thermal, breadboard, and connected-device limits.
- For a 3.3 V load, prefer a 9 V or higher PD input profile as documented in the electrical notes.

## 6 Mechanical Information


Mechanical dimensions in millimeters

All dimensions in the drawing are in millimeters. The board is designed to align with common 54 mm and 64 mm solderless-breadboard rail formats. Confirm actual clearance around the USB-C connector, screw terminal, jumper caps, and Qwiic cable before final assembly.

### 6.1 Installation Notes

Support the board while inserting or removing it from a breadboard to avoid bending headers. Do not use the Qwiic cable or USB-C cable as a mechanical support. Keep adequate clearance for wiring attached to the VUSB terminal and for heat dissipation from the regulator under load.

## 7 Company Information

Item | Value
Company | UNIT Electronics
Website | https://uelectronics.com/
Address | Salvador 19, Cuauhtémoc, 06000, Mexico City, CDMX, Mexico
Product family | DevLab

For product support, current documentation, and software examples, use the product wiki and repository listed in the next chapter.

## 8 Reference Documentation

Reference | Link or repository file
Product wiki | Power Supply for Breadboard with Qwiic wiki (https://wiki.uelectronics.com/wiki/unit_devlab_power_supply_for_breadboard_with_qwiic)
Source repository | UNIT-Electronics-MX/unit_devlab_power_supply_for_breadboard_with_qwiic (https://github.com/UNIT-Electronics-MX/unit_devlab_power_supply_for_breadboard_with_qwiic)
Board schematic | V1.0 schematic (https://github.com/UNIT-Electronics-MX/unit_devlab_power_supply_for_breadboard_with_qwiic/blob/main/hardware/unit_sch_v_1_0_0_ue0113_devlab_power_supply_for_b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)
General pinout | English pinout (https://github.com/UNIT-Electronics-MX/unit_devlab_power_supply_for_breadboard_with_qwiic/blob/main/hardware/unit_pinout_v_1_0_0_ue00113_Power_Supply_for_Brea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)
HUSB238 controller | hardware/resources/unit_datasheet_v_1_0_0_ue0113_husb238.pdf
TPS54302 regulator | hardware/resources/unit_datasheet_v_1_0_0_ue0113_tps54302.pdf
Arduino IDE | arduino.cc/en/software

Component datasheets describe the individual devices. The ratings and mechanical information in this reference remain specific to the UE0113 module.

## 9 Appendix

### 9.1 Source Migration

This editable product reference is migrated from the released PDF:

hardware/unit_datasheet_v_1_0_0_ue0113_Power_Supply_for_Breadboard_with_Qwiic.pdf

The original PDF is retained as a released historical artifact. The Markdown chapters under tools/product-reference/chapters/ are the source for future generated PDF and DOCX editions.

### 9.2 Documentation Scope

The module’s negotiated VUSB output depends on the USB-C PD source and cable. The listed component ratings do not independently establish all module-level limits. Before high-voltage or high-current use, verify the selected profile, measure the output, and account for all connected hardware.

The released V1.0 datasheet mentions an 18 V PD profile in descriptive text, while its ratings tables enumerate 5 V, 9 V, 12 V, 15 V, and 20 V. This reference treats 18 V as source-dependent rather than as a guaranteed standard profile.

### 9.3 Document Control

Item | Value
Product reference version | 1.0.0
Hardware revision | V1.0
Manufacturer part number | UE0113
Released datasheet date | 2026-06-30
Editable source | tools/product-reference/

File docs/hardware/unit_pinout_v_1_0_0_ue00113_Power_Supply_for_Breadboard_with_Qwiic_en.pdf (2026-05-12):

# PINOUT

# DevLab: Power Supply for Breadboard with Qwiic

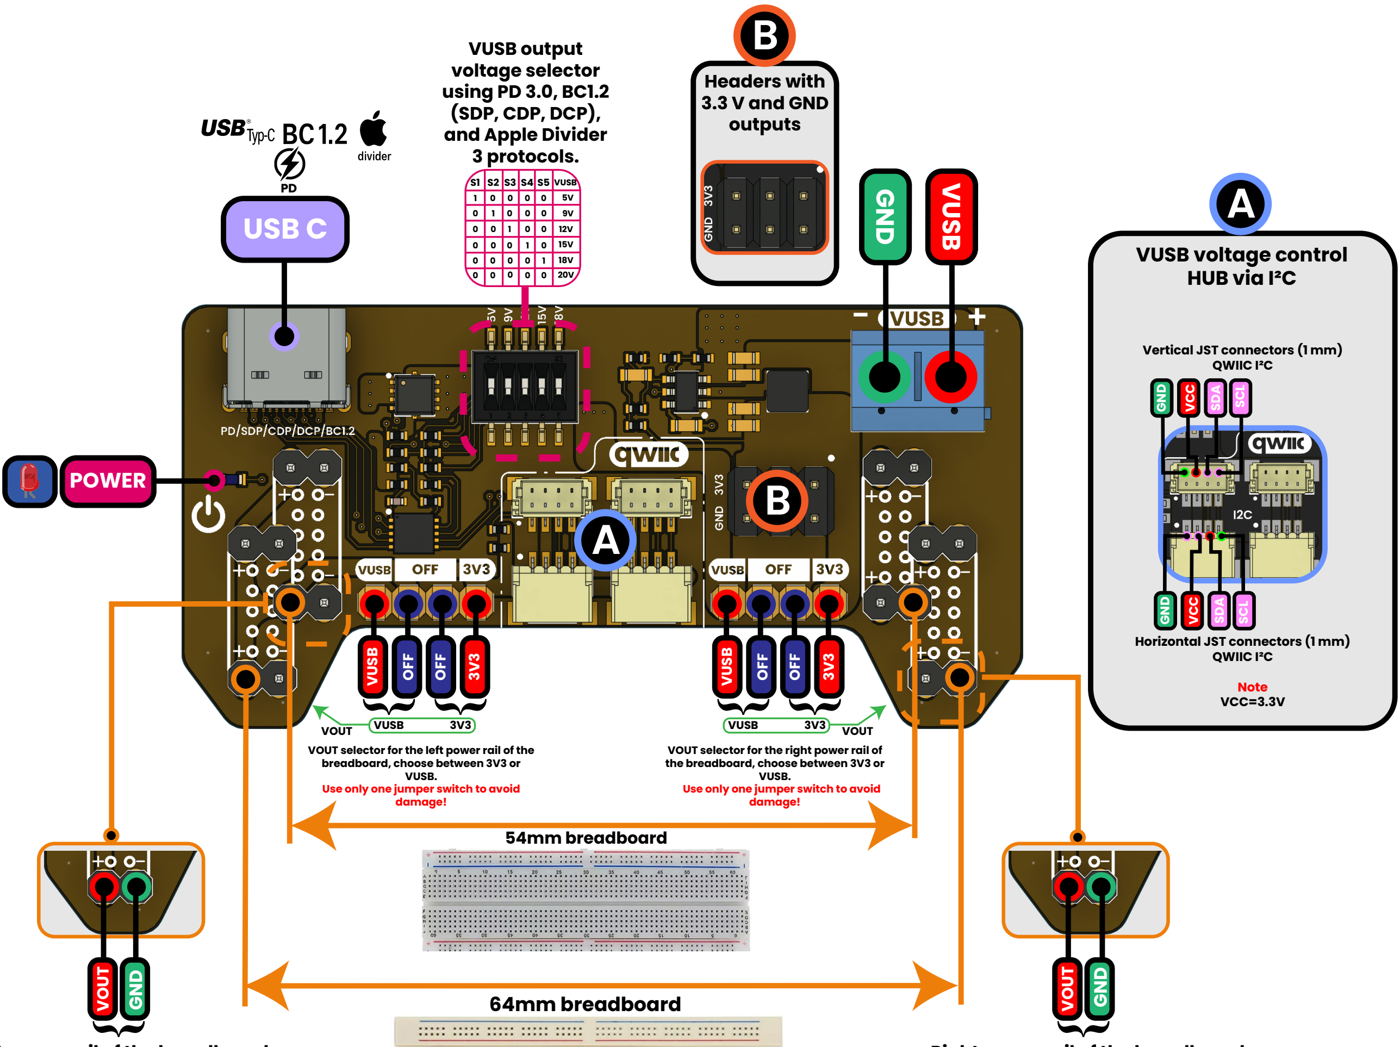
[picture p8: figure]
PD USB C; VUSB output voltage selector using PD 3.0, BC1.2 (SDP, CDP, DCP), and Apple Divider 3 protocols.; VUSB 5V 9V 12V 15V 18V; POWER; VUSB; OFF; GND; }VOUT GND; 3V3 VOUT; }VUSB; breadboard, choose between 3V3 or VUSB. Use only one jumper switch to avoid damage!; the breadboard, choose between 3V3 or VUSB. Use only one jumper switch to avoid damage!; 54mm breadboard; 64mm breadboard; Vertical JST connectors (1 mm) QWIIC I²C; VUSB voltage control HUB via I²C; Horizontal JST connectors (1 mm) QWIIC I²C; Headers with 3.3 V and GND outputs; VCC; SDA; SCL; Note VCC=3.3V
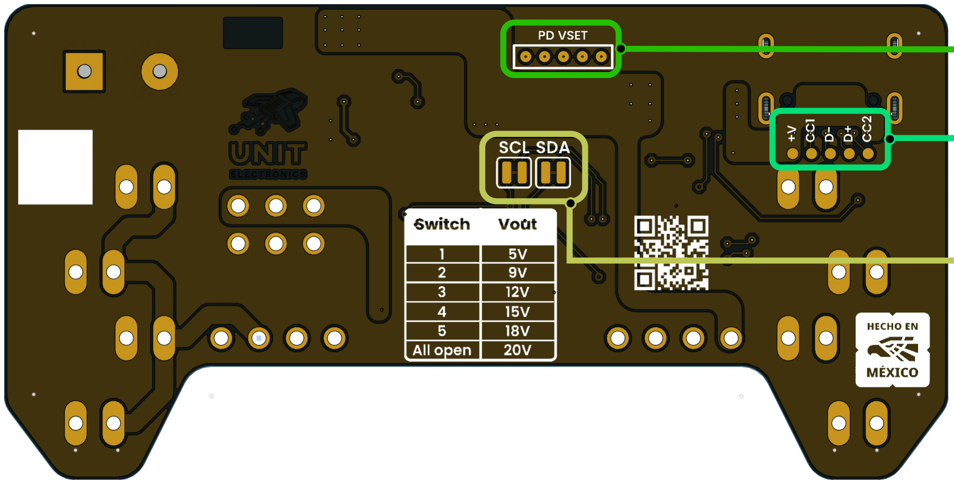
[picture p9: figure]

Apple™, Divider™, USB Battery Charging 1.2™, USB Type-C™, and USB Power Delivery™ logos are registered trademarks of their respective owners. Their use in this document is for illustrative and educational purposes only.

VOUT selector for the left power rail of the

VOUT selector for the right power rail of

Left power rail of the breadboard | Right power rail of the breadboard

“PD lines test points”

“USB lines test points”

“Jumper pads”
Open these pads if the HUB is intended only for device connectivity and VUSB control via I²C is not required.

# Top view

# Bottom view

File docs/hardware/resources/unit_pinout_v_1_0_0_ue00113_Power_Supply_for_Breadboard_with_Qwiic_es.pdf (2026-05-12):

# PINOUT

# DevLab: Power Supply for Breadboard with Qwiic

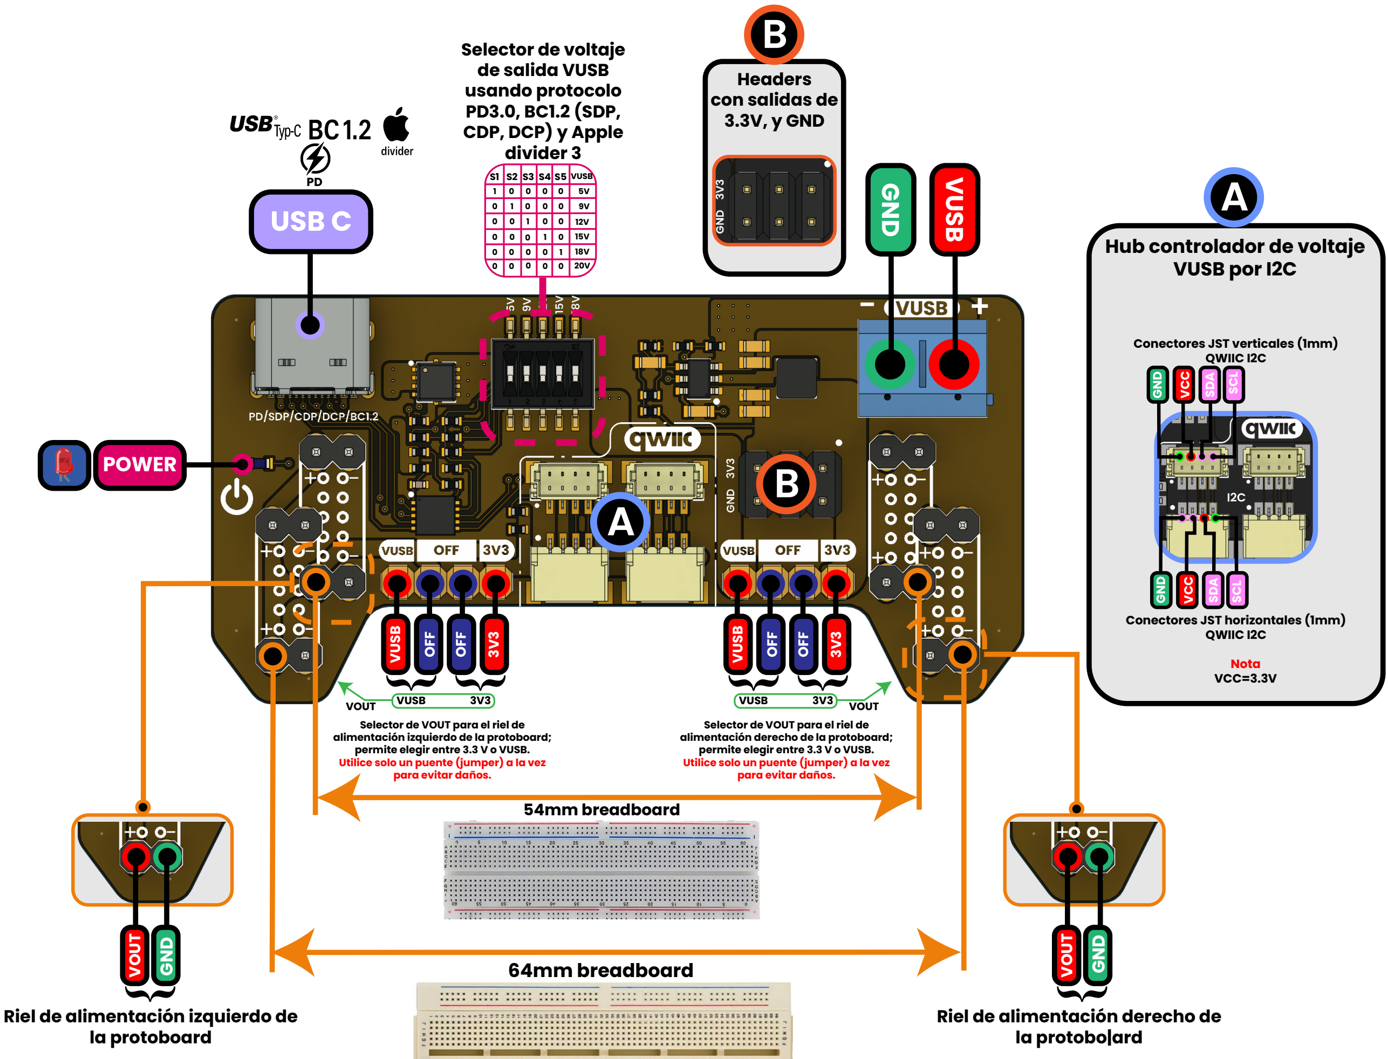
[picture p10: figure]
PD USB C; Selector de voltaje de salida VUSB usando protocolo PD3.0, BC1.2 (SDP, CDP, DCP) y Apple divider 3; VUSB 5V 9V 12V 15V 18V; POWER; VUSB; OFF; GND; }VOUT GND; 3V3 VOUT; }VUSB; Selector de VOUT para el riel de alimentación izquierdo de la protoboard; permite elegir entre 3.3 V o VUSB. para evitar daños.; Selector de VOUT para el riel de alimentación derecho de la protoboard; permite elegir entre 3.3 V o VUSB. para evitar daños.; 54mm breadboard; 64mm breadboard; Riel de alimentación izquierdo de la protoboard; Riel de alimentación derecho de la protobo|ard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

Los logotipos Apple™, Divider™, USB Battery Charging 1.2™, USB Type C y USB Power Delivery™ son marcas registradas de sus respectivos propietarios, su uso en este documento es únicamente con fines ilustrativos y educativos.

Utilice solo un puente (jumper) a la vez

Utilice solo un puente (jumper) a la vez

“Test points para lineas PD”

“Test points para lineas de USB”

“Jumper pads”
Abrirlos si solo se desea utilizar el HUB para conectar dispositivos y no controlar VUSB por I2C

# Vista superior

# Vista inferior

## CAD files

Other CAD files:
docs/hardware/mechanics/unit_3d_v_1_0_0_ue0113_Power_Supply_for_Breadboard.f3z

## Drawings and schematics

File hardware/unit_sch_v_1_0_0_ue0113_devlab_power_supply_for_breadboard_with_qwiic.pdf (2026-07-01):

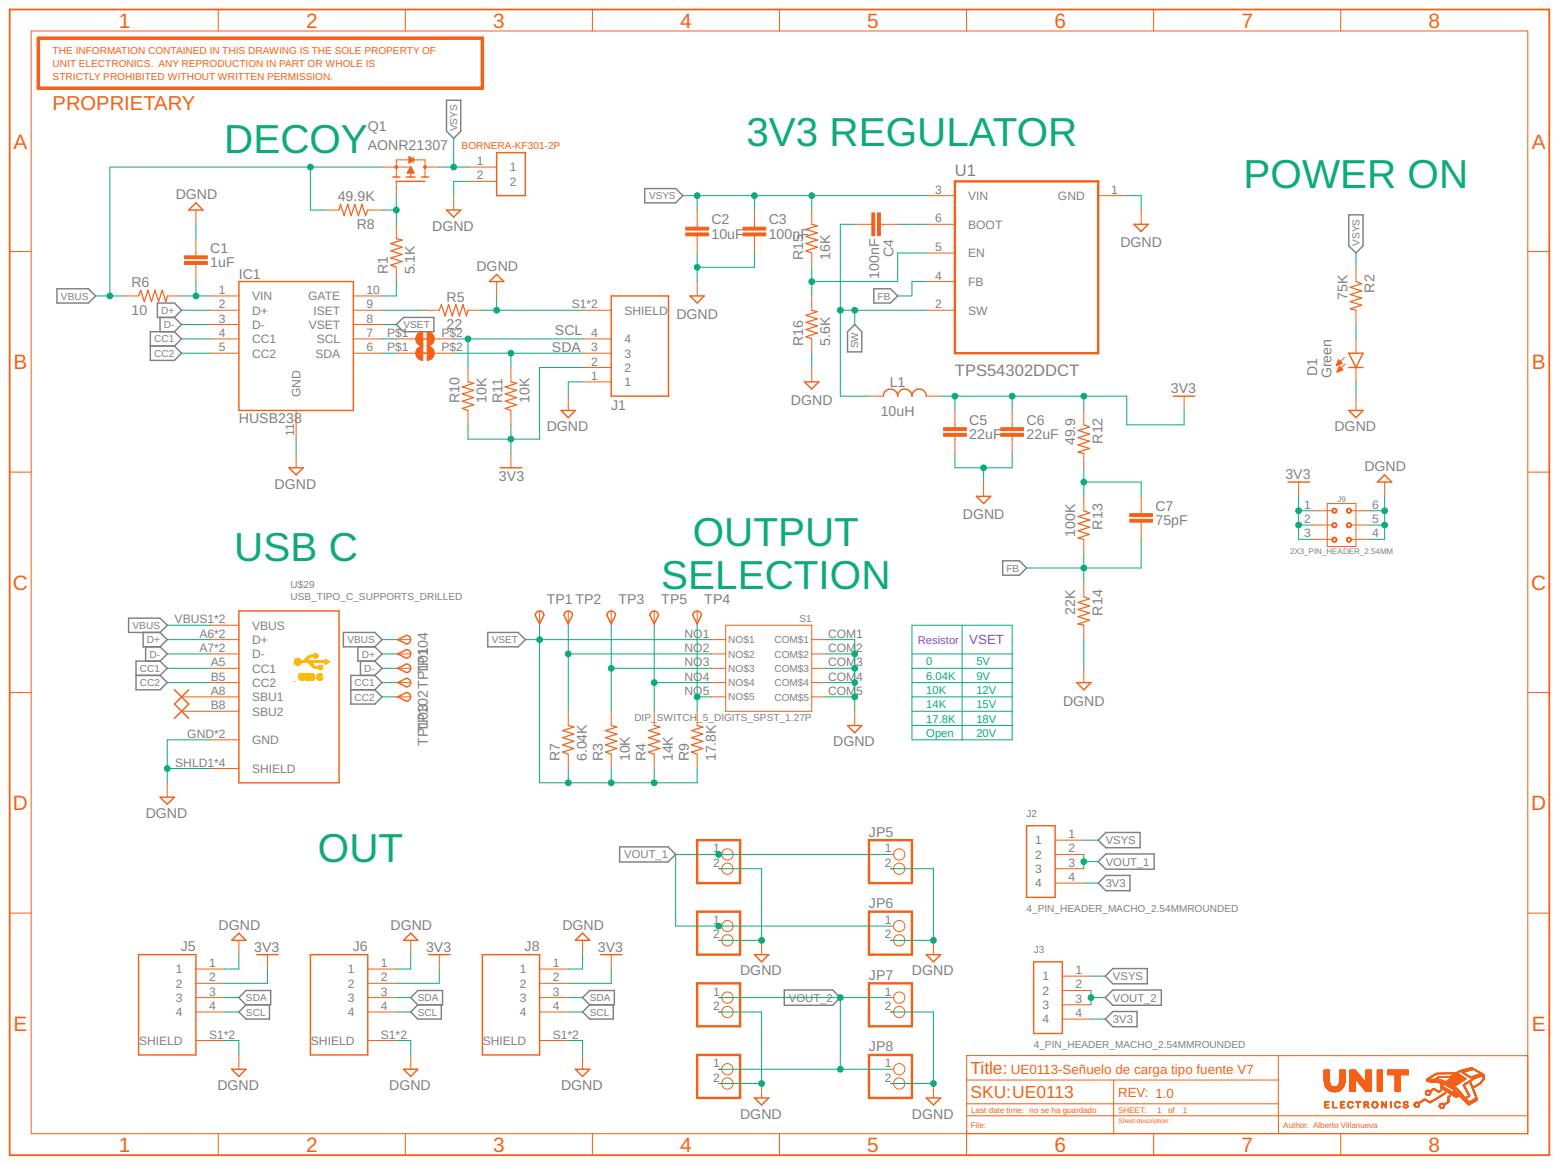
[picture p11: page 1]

THE INFORMATION CONTAINED IN THIS DRAWING IS THE SOLE PROPERTY OF UNIT ELECTRONICS. ANY REPRODUCTION IN PART OR WHOLE IS

STRICTLY PROHIBITED WITHOUT WRITTEN PERMISSION. PROPRIETARY

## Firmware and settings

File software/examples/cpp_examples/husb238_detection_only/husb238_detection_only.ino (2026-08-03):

/**
 * HUSB238 USB-C PD source detection C++ example.
 *
 * Detects the HUSB238 over I2C and prints the voltage profiles offered by
 * the connected USB-C PD source.
 */

#include <Wire.h>
#include <Adafruit_HUSB238.h>

// Change these values to match the I2C pins on the controller connected to
// the module. The defaults are suitable for UNIT Electronics RP2040 boards.
#ifndef HUSB238_I2C_SDA
#define HUSB238_I2C_SDA 6
#endif

#ifndef HUSB238_I2C_SCL
#define HUSB238_I2C_SCL 7
#endif

Adafruit_HUSB238 husb238;
bool husb238Ready = false;

void printDetectedVoltages() {
  bool anyVoltage = false;

  Serial.println("Available USB-C PD voltages:");

  if (husb238.isVoltageDetected(PD_SRC_5V)) {
    Serial.println("- 5 V");
    anyVoltage = true;
  }
  if (husb238.isVoltageDetected(PD_SRC_9V)) {
    Serial.println("- 9 V");
    anyVoltage = true;
  }
  if (husb238.isVoltageDetected(PD_SRC_12V)) {
    Serial.println("- 12 V");
    anyVoltage = true;
  }
  if (husb238.isVoltageDetected(PD_SRC_15V)) {
    Serial.println("- 15 V");
    anyVoltage = true;
  }
  if (husb238.isVoltageDetected(PD_SRC_18V)) {
    Serial.println("- 18 V");
    anyVoltage = true;
  }
  if (husb238.isVoltageDetected(PD_SRC_20V)) {
    Serial.println("- 20 V");
    anyVoltage = true;
  }

  if (!anyVoltage) {
    Serial.println("- No USB-C PD profile detected");
  }
}

void setup() {
  Serial.begin(115200);
  delay(1000);

  Wire.begin(HUSB238_I2C_SDA, HUSB238_I2C_SCL);
  delay(100);

  Serial.println("Initializing HUSB238...");
  husb238Ready = husb238.begin(HUSB238_I2CADDR_DEFAULT, &Wire);

  if (husb238Ready) {
    Serial.println("HUSB238 detected.");
  } else {
    Serial.println("HUSB238 not found. Check the I2C connection and pins.");
  }
}

void loop() {
  if (!husb238Ready) {
    delay(1000);
    return;
  }

  printDetectedVoltages();
  Serial.println();
  delay(1000);
}

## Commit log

2026-05-12 Revise README to enhance module description and applications
    Updated introduction and applications sections to provide detailed information about the Breadboard Power Supply module and its use cases.
2026-05-12 Update README with notes on USB Power Delivery and regulator
2026-05-26 docs: rename schematic to sch*
2026-07-01 docs: add 3d models
    [unit_3d_v_1_0_0_ue0113_Power_Supply_for_Breadboard.f3z]
2026-07-01 Auto-update hardware documentation [skip ci]
    [unit_3d_v_1_0_0_ue0113_Power_Supply_for_Breadboard.f3z]
2026-07-01 docs: update schematics
2026-08-03 docs: add voltage reference image
2026-08-14 chore: add component CAD assets publishing workflow
2026-08-14 ci: publish CAD assets only in docs
2026-08-14 fix: remove generated CAD assets from mechanics source
